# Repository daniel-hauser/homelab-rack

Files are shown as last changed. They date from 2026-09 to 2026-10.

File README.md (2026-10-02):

# Modular printable homelab rack

A parameterized, support-free OpenSCAD rack for a desktop stack today and
paired half-width modules in a standard 19-inch rack later. The current build
holds a UCG-Ultra, two USW-Ultra units, two Raspberry Pi 5 drawers, a removable
vent insert, and a UK-Ultra top carrier.

[**Start with `PRINT_THESE`**](PRINT_THESE/) ·
[3D viewer](https://daniel-hauser.github.io/homelab-rack/) ·
[rack render](renders/rack_preview_final.png) ·
[all build plates](renders/beds/all_beds.png)

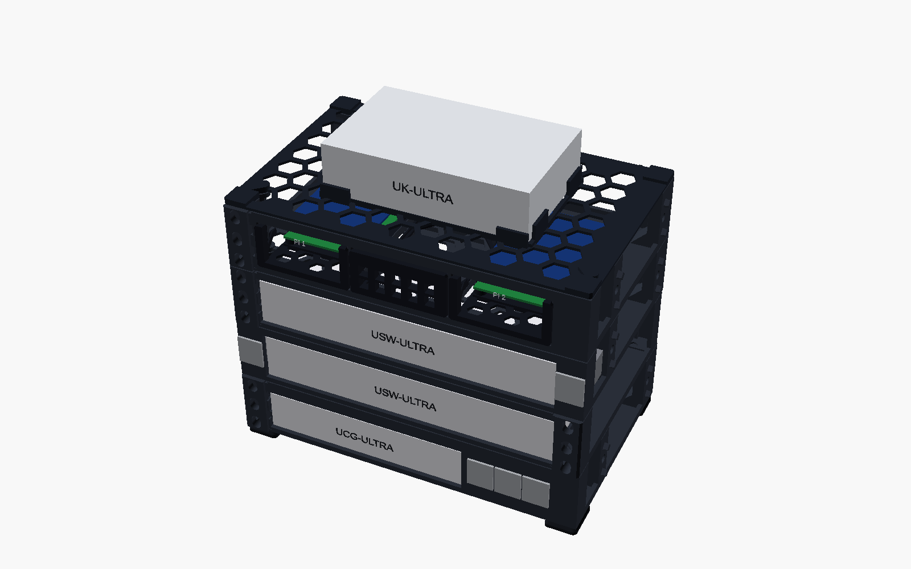
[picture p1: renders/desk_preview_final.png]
Assembled desktop homelab rack


## Choose the right project

### Already printed the older test-first plate

Open
[`PRINT_THESE\homelab-rack-Bambu-Studio-5-plates-NO-TEST.3mf`](PRINT_THESE/homelab-rack-Bambu-Studio-5-plates-NO-TEST.3mf)
or double-click `PRINT_THESE\OPEN_NO_TEST_PROJECT.cmd`. This is the optimized
production project: five A1 visits, no coupons, no polarity key, every final
assembly object exactly once, and one deliberately small manual support.
The optional
[`homelab-rack-Bambu-Studio-5-plates-NO-TEST-NO-SUPPORT.3mf`](PRINT_THESE/homelab-rack-Bambu-Studio-5-plates-NO-TEST-NO-SUPPORT.3mf)
preserves the native A/B baseline.

The project deliberately includes the current
`TEST_FIRST\04_Desktop_Feet_Set.stl`. The foot-to-stack peg and magnet geometry
changed, so feet from the older test plate are obsolete. No other test-only
artifact is required. The revised vent and both rear spines are already
included as final production objects.

### Waveshare PoE M.2 HAT+ (B) clearance replacement

If the dual-Pi chassis has not yet been printed, use
[`PRINT_THESE\REPLACEMENTS\PI-HAT-5MM-CLEARANCE`](PRINT_THESE/REPLACEMENTS/PI-HAT-5MM-CLEARANCE)
instead of the `04_Dual_Pi_Chassis.stl` object on Plate 3. This isolated
replacement raises only the two Pi openings from 30 mm to 35 mm for the HAT's
top power coils. The center vent opening, existing drawers, magnetic holders,
vent cartridge, rails, detents, and every stack/rack interface remain
unchanged; do not reprint the drawers or vent.

### Pi drawer 6 mm magnet-pocket replacement

If nominal 6 mm magnets do not enter the original drawer pockets, use
[`PRINT_THESE\REPLACEMENTS\PI-MAGNET-POCKET-6MM`](PRINT_THESE/REPLACEMENTS/PI-MAGNET-POCKET-6MM).
These replace both Pi drawers only. Their 6.60 mm straight glue-fit bores have
7.00 mm flared bed-face entrances to avoid elephant-foot constriction. Do not
press-fit magnets or drill through the 0.30 mm insulating roof; glue each
magnet against the roof after confirming polarity. The chassis and vent remain
unchanged.

### Complete remaining Pi hardware on one plate

For users who still need the corrected chassis and both corrected drawers, use
[`PRINT_THESE\REPLACEMENTS\PI-COMPLETE-SINGLE-PLATE`](PRINT_THESE/REPLACEMENTS/PI-COMPLETE-SINGLE-PLATE).
Its A1 project contains exactly those three objects on one plate, preserves the
validated chassis-only front-rail supports, and excludes the already-printed
vent.

| Plate | Objects |
| --- | --- |
| 1 | UCG-Ultra module; rear spine A |
| 2 | left USW-Ultra module; rear spine B |
| 3 | dual-Pi chassis; final rail-guided vent cartridge |
| 4 | right USW-Ultra module; Pi drawer 2 |
| 5 | UK-Ultra top; Pi drawer 1; revised desktop feet set |

The recommended targeted-support estimate is **517.58 g**, **173.53468 m**,
**417.39985 cm³**, and **23h13m19s** serial printing time. It adds **0.88 g**
and **6m23s** over the no-support baseline. Five plates remain the
geometric lower bound: the four chassis and the UK-Ultra top each have an
axis-aligned footprint wider than 241 mm and deeper than 150 mm, so no two fit
on one 256 × 256 mm A1 plate without overlap. Smaller parts occupy otherwise
unused bed regions around those five unavoidable footprints.

### Have not printed a test plate

Use the numbered files exactly as tracked. Do not use old aliases from previous
design revisions.

1. Open
   [`PRINT_THESE\TEST_FIRST\plate_1-test.3mf`](PRINT_THESE/TEST_FIRST/plate_1-test.3mf)
   in **Bambu Studio 02.08.02.61**, or import these ten STLs individually:

   - `PRINT_THESE\TEST_FIRST\01_Bay_Fit_Test.stl`
   - `PRINT_THESE\TEST_FIRST\02_Rear_Spine_A.stl`
   - `PRINT_THESE\TEST_FIRST\03_Rear_Spine_B.stl`
   - `PRINT_THESE\TEST_FIRST\04_Desktop_Feet_Set.stl`
   - `PRINT_THESE\TEST_FIRST\05_Magnet_Keystone_Peg_Test.stl`
   - `PRINT_THESE\TEST_FIRST\06_Vent_Insert.stl`
   - `PRINT_THESE\TEST_FIRST\07_Magnet_Polarity_Key.stl`
   - `PRINT_THESE\TEST_FIRST\08_Rack_Ear_Test.stl`
   - `PRINT_THESE\TEST_FIRST\09_Seam_Tower_Male_Test.stl`
   - `PRINT_THESE\TEST_FIRST\10_Seam_Tower_Female_Test.stl`

2. Break off and mate the stack tiles, then confirm the magnet pockets,
   keystone opening, Pi bay, seam towers, and rack-ear slots fit your hardware.
3. If the test plate succeeds, open the original test-first project,
   [`PRINT_THESE\homelab-rack-Bambu-Studio-6-plates.3mf`](PRINT_THESE/homelab-rack-Bambu-Studio-6-plates.3mf)
   or double-click `PRINT_THESE\OPEN_IN_BAMBU_STUDIO.cmd`.
4. Keep the rear spines flat on their broad faces. All tracked STLs are already
   exported in their intended print orientation.

Both projects use a Bambu Lab A1 with a 0.4 mm nozzle, 0.20 mm layers,
four walls, five top layers, four bottom layers, 20% gyroid, no supports, no
brim, and no skirt. The original six-plate magnetic-direction estimate is
**547.11 g**, **183.43948 m**, **441.22368 cm³**, and **24h43m51s** serial
printing time. Loose-magnet attraction to all four assembled Pi/HAT screw
heads has passed physical testing.

Bambu Studio reports a conservative “floating cantilever/regions” warning on the four
full-height chassis. Their maximum measured bridge is 17.52 mm. Print plate 1
first; if both seam-tower coupons are clean, keep automatic supports disabled
for the production chassis because generated supports obstruct functional
pockets and fill large open areas.

Native A/B slicing found no roof over the UCG or USW device cavities. The
17.51–17.52 mm upper paths are forward seam-side corner-cap bridges; the
seam-tower paths are shorter and farther rearward. The recommended project
adds one reachable 7 × 7 mm manual support column beneath that cap on the UCG.
It starts on the internal bottom cap because the
enclosed corner-post cavity is not reachable from the build plate.

The same seam-side location on each USW intersects its 34 mm-deep keystone
clearance; the opposite cap is the rack-ear/slot region. Both USWs therefore
remain unsupported rather than placing material in protected geometry for a
17.52 mm bridge that already passes the native bridge gate.

No support is generated around magnet pockets, peg/socket interfaces, seam
keys or towers, rack-ear slots, device rails, keystone openings, rear-spine
interfaces, or rear corner cavities. Support toolpath renders are under
`renders\supports-no-test`. The maximum classified bridge remains 18.84 mm
(the revised feet); supported chassis bridge lines remain classified as
bridges because of the removable 0.2 mm support gap.

Bambu clears the floating-region banner globally when manual support mode is
enabled, including on plates with no support extrusion. The A/B audit therefore
uses actual support toolpath segments—not warning disappearance—as its gate.

## Production STLs

`PRINT_THESE\STLs` contains only the ten required production files:

| File | Part |
| --- | --- |
| `01_UCG_Ultra.stl` | UCG-Ultra module |
| `02_USW_Ultra_Left.stl` | left USW-Ultra module |
| `03_USW_Ultra_Right.stl` | right USW-Ultra module |
| `04_Dual_Pi_Chassis.stl` | three-bay dual-Pi chassis |
| `05_Pi_Drawer_1.stl` | first Pi 5 drawer |
| `06_Pi_Drawer_2.stl` | second Pi 5 drawer |
| `07_Vent_Insert.stl` | center bay vent |
| `08_UK_Ultra_Top.stl` | desktop UK-Ultra carrier |
| `09_Rear_Spine_A.stl` | first rear spine |
| `10_Rear_Spine_B.stl` | second rear spine |

The two rear-spine files are intentionally identical; print both. The removable
feet are on the test-first plate.

## Design summary

- Half-module structural footprint: 241.30 × 150.00 mm.
- Paired width: 482.60 mm, with 465.10 mm rack mounting centers.
- Rack pitch: 44.45 mm; vertical hole centers: 6.350, 22.225, 38.100 mm.
- Universal magnets: 6 × 2 mm discs.
- Vertical registration: four printed peg/socket pairs plus four magnet pairs
  at every module-to-module or module-to-cap interface.
- Side joining: tapered diamond keys in reinforced seam towers.
- Paired seam: 0.0 mm designed face gap with 1.5 mm socket-depth reserve.
- Desktop stabilization: two removable rear spines and four removable feet.
- Pi mounting direction: four 6 × 2 mm magnets beneath the existing exposed
  lower screw heads, with printed side/corner locators carrying shear.
- Exposed chassis/top corners: 1.5 mm support-free chamfers.
- Pi and vent faceplates: 1.2 mm chamfers.
- Pi bay receiving lead-in: 1.2 mm deep at 45°, opening to 64.4 × 32.4 mm at
  the front while retaining the 62 × 30 mm friction opening behind it.
- Vent cartridge: 111 mm L-section side runners with 77 mm of guide-lip
  engagement and a light rear chevron that prevents racking.

Loose 6 × 2 mm magnets physically attract all four intended lower screw heads,
so screw ferromagnetism is accepted. The current CAD assumptions remain a
1.60 mm screw-head protrusion, 0.35 mm working gap, and 0.30 mm printed
insulating skin. Validate the actual installed gap and retention on the first
production drawer before printing the second. The through-floor concept
remains review-only because it requires replacement screws. Review CAD and the
full measurement list are in
[`REVIEW_ONLY\Pi_Mount_Alternatives`](REVIEW_ONLY/Pi_Mount_Alternatives).

Do not print another test coupon for the Pi mount. Print only
`PRINT_THESE\STLs\05_Pi_Drawer_1.stl` first with the pinned production profile,
install four magnets, seat the actual Pi/HAT assembly, and verify vertical
retention, locator engagement, drawer insertion, and the installed holder gap.
Print Drawer 2 only after that first article passes.

The vent is a proper track-guided cartridge rather than a shallow friction
plate. Its proven 64.5 × 30 mm face is unchanged. Two long L-section runners
engage the same floor tracks and guide lips as the Pi drawers, with 0.15 mm
side clearance and 2.0 mm reserve before the chassis rear stop. Two
inward-rising rear chevron legs prevent racking while leaving the airflow path
open. The cartridge prints face-down; each chevron leg grows from a supported
runner and keeps the maximum slicer-classified bridge below 20 mm.

The vent and both Pi cartridges share paired cam-release spring detents. The
detent pockets have 0.20 mm more depth than the 0.45 mm engagement, so they
provide pull-out retention without defining lateral alignment or
overconstraining the guide tracks. Push straight in until both sides click and
the receiving chamfer seats the faceplate flush. Remove by gripping the
projecting faceplate edges and pulling evenly; the rear ramps flex both
detents inward without tools.

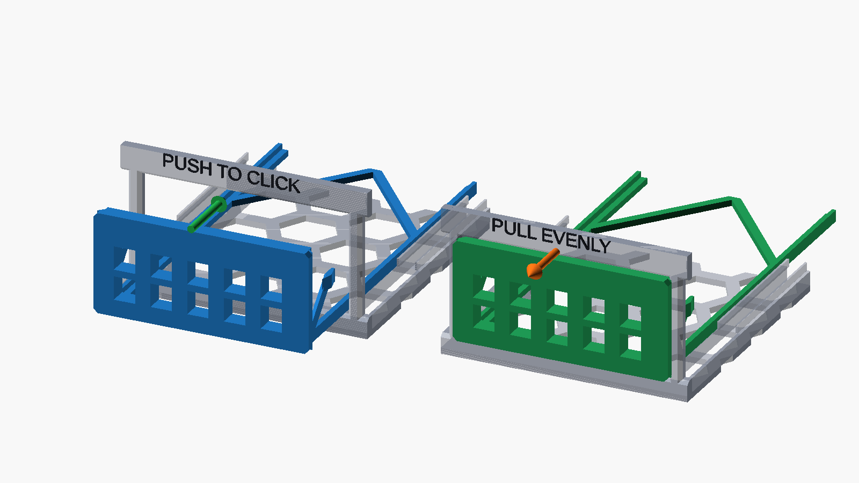
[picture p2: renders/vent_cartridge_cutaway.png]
Vent cartridge insertion and removal cutaway


Rack-stack magnets retain joints while printed pegs and keys carry lateral
loads. The Pi magnets provide vertical retention only; their printed locators
carry shear. A 19-inch installation still requires normal rack screws and cage
nuts. The UK-Ultra carrier assumes the OEM keyed backplate/cradle remains
attached.

Each vertical module interface has magnet centers at `(8,20)`, `(233.3,20)`,
`(8,142)`, and `(233.3,142)` mm, with independent peg/socket centers at
`(13,25)`, `(228.3,25)`, `(13,137)`, and `(228.3,137)` mm. The front pairs sit
behind the rack-slot cut depth; the closest magnet pocket retains 0.675 mm of
clearance and the closest socket retains 6.15 mm. The pattern is identical on
all full modules and the cap, so handed rack ears cannot create
magnet-to-empty-pocket pairs.

The desktop stack has 20 vertical magnet pairs: four at each of the four
module/cap joints plus four foot-to-bottom-module pairs. Two rear spines add
eight horizontal pairs, two per module. They align and brace the rear of the
four-module stack against racking but do not replace vertical corner
clamping. With eight Pi-retention magnets, the fully populated desktop build
uses 64 magnets.

Use one marked pole consistently by global axis:

- Stack and foot magnets: marked face points globally up (`+Z`).
- Module/spine rear magnets: marked face points toward the rack rear (`+Y`).
- Future side-seam magnets: marked face points toward rack right (`+X`).
- Pi magnets attract steel screw heads, so polarity is not functional; use the
  marked face upward for installation consistency.

Run the analytical checks before changing structural parameters:

```powershell
python .\rack_check.py
python .\load_check.py
python .\release_check.py
```

The current conservative screening reports a 2.6× honeycomb yield safety
factor, 93× stack-peg shear safety, 158.5× side-key shear safety, 7.9×
side-key interlayer bending safety, and 3.7× seam-tower interlayer safety.
These calculations do not replace a physical proof load.

## Reproduce or verify the release

The canonical geometry source is [`homelab_rack.scad`](homelab_rack.scad).
The release is pinned to:

- **OpenSCAD 2021.01** for STL and canonical CAD render generation.
- **Bambu Studio 02.08.02.61** for arrangement, slicing, estimates, and 3MF
  output.
- Python 3.13 with the pinned packages in `requirements.txt`.
- Node.js 22 with dependencies locked by `viewer\package-lock.json`.

Install Python dependencies:

```powershell
python -m pip install -r .\requirements.txt
```

Use one workflow for all OpenSCAD-derived release assets:

```powershell
# Export to ignored out\release-work and hash-check all tracked release assets.
.\export.ps1 -Mode Verify

# Deliberately replace the 20 numbered STLs, 11 viewer meshes,
# five canonical renders, and viewer estimate copy.
.\export.ps1 -Mode Generate
```

`Verify` compares fresh OpenSCAD exports with:

- all ten `PRINT_THESE\STLs` files using order-independent mesh hashes;
- all ten `PRINT_THESE\TEST_FIRST` files using order-independent mesh hashes;
- ten viewer production copies plus the viewer-only installed-feet model using
  the same geometry check;
- the five canonical CAD renders pixel-for-pixel, ignoring harmless PNG
  compression differences; and
- `viewer\public\estimate.json` against `slicer\release\estimate.json`.

The mesh hash ignores harmless STL facet ordering differences between
OpenSCAD runs. The tracked binary artifacts and their published SHA-256 hashes
are not changed by `Verify`.

### Bambu Studio / 3MF boundary

The repository automates same-named mesh replacement while preserving an
existing Bambu arrangement, but it does **not** automate Bambu Studio itself.
After changing geometry, first run `export.ps1 -Mode Generate`, then create
unsliced arrangement copies:

```powershell
python .\slicer\replace_3mf_meshes.py `
  .\PRINT_THESE\homelab-rack-Bambu-Studio-6-plates.3mf `
  .\out\homelab-rack-arranged-unsliced.3mf `
  .\PRINT_THESE\STLs .\PRINT_THESE\TEST_FIRST

python .\slicer\replace_3mf_meshes.py `
  .\PRINT_THESE\TEST_FIRST\plate_1-test.3mf `
  .\out\plate_1-arranged-unsliced.3mf `
  .\PRINT_THESE\STLs .\PRINT_THESE\TEST_FIRST
```

When only a subset changed, pass `--skip-missing` with a directory containing
only those STLs. This preserves the validated triangulation and arrangement of
every unaffected project mesh while still removing stale embedded G-code.

Open those copies in **Bambu Studio 02.08.02.61**, confirm the pinned A1
profile, slice every plate, inspect warnings, and save the final projects over
the tracked release 3MF files only after validation. This slicer step is
required: the replacement tool intentionally removes stale embedded G-code.

Raw `.gcode` and `.gcode.3mf` work products are ignored and are **not** tracked
release inputs. When fresh Bambu outputs exist locally, bridge audits and bed
renders can be regenerated with:

```powershell
python .\slicer\bridge_audit.py `
  .\slicer\production\desktop-strong `
  --project .\PRINT_THESE\homelab-rack-Bambu-Studio-6-plates.3mf `
  --output .\bridge-audit.json

python .\slicer\render_beds.py `
  .\slicer\production\desktop-strong `
  .\slicer\production\desktop-strong\desktop-strong.gcode.3mf `
  .\renders\beds
```

The separated five-plate evidence is tracked in:

- `slicer\release\no-test-estimate.json`
- `slicer\release\no-test-bridge-audit.json`
- `slicer\release\no-test-no-support-estimate.json`
- `slicer\release\no-test-no-support-bridge-audit.json`
- `slicer\release\no-test-support-ab-audit.json`
- `renders\beds-no-test`
- `renders\supports-no-test`

## Viewer

The public viewer is deployed by GitHub Pages without repository secrets:
<https://daniel-hauser.github.io/homelab-rack/>.

Local build:

```powershell
Set-Location .\viewer
npm ci
npm run build
```

The viewer uses relative asset paths, so it works under the repository Pages
subpath. Its displayed release totals come from
`viewer\public\estimate.json`, synchronized from the slicer estimate by
`export.ps1`.

## Dimensions to verify physically

Manufacturer envelopes are sufficient for the adjustable cradles, but verify
these before a long print:

- UCG-Ultra and USW-Ultra corner radii;
- assembled Pi 5, cooler, HAT, and NVMe height;
- keystone latch depth and panel-thickness requirements; and
- cable boot bend radius behind each rear-facing port.

Sources: [UCG-Ultra](https://techspecs.ui.com/unifi/cloud-gateways/ucg-ultra),
[USW-Ultra](https://techspecs.ui.com/unifi/switching/usw-ultra),
[UK-Ultra](https://techspecs.ui.com/unifi/wifi/uk-ultra),
[Waveshare PoE M.2 HAT+ (B)](https://www.waveshare.com/poe-m.2-hat-plus-b.htm),
[Raspberry Pi 5 mechanical drawing](https://datasheets.raspberrypi.com/rpi5/raspberry-pi-5-mechanical-drawing.pdf),
and [Bambu Lab A1](https://bambulab.com/en/a1/tech-specs).

## License

See [`LICENSE.md`](LICENSE.md). Hardware sources and generated hardware
artifacts are CERN-OHL-S-2.0, software/tooling is MIT, and documentation and
rendered images are CC-BY-4.0.

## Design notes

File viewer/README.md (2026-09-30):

# Homelab Rack 3D Viewer

Focused Vite + TypeScript + Three.js viewer for the validated ten-part homelab
rack production set. Dependencies and STL assets are local; the deployed site
makes no CDN requests.

## Local development

```powershell
npm ci
npm run dev
```

Production build:

```powershell
npm run build
```

The output is written to `dist`. Vite uses `base: "./"`, so scripts, images, and models resolve beneath any GitHub Pages repository subpath.

## GitHub Pages integration

The repository workflow at `.github/workflows/pages.yml` builds this directory
with Node 22 and publishes `viewer/dist` through GitHub's OIDC-backed Pages
deployment. It uses no repository secrets.

No repository name or fixed `/repo/` base path is embedded. Relative Vite paths
allow the site to run at `https://daniel-hauser.github.io/homelab-rack/`.

## Production data

- Printer: Bambu Lab A1, 0.4 mm nozzle
- Profile: 0.20 mm layers, four walls, five top/bottom layers, 20% gyroid
- Supports/brim/skirt: none
- Candidate total: 547.11 g, 183.43948 m, 441.22368 cm³, 24h43m51s
- Magnets: universal 6 × 2 mm discs
- Module depth: 150 mm

Dimensions shown in the viewer are calculated STL bounding boxes. Release
totals are loaded from `public/estimate.json`, which `..\export.ps1`
synchronizes with `slicer/release/estimate.json`.

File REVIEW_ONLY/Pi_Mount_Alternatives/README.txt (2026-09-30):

PI MOUNT ALTERNATIVES - REVIEW ONLY
===================================

These files document the selected magnetic Raspberry Pi 5 mounting direction
and its through-floor fallback. Loose-magnet attraction has passed on all four
assembled screw heads. Exact installed holder gap and retention remain a
production Drawer 1 first-article check.

A_Magnetic_Cradle_Review.stl - selected direction, physically gated
  Four 6 x 2 mm magnet glue pockets align to the accessible lower screw heads
  on the official 58 x 49 mm Pi pattern. A provisional 0.30 mm printed
  insulating skin separates each magnet from the screw-head recess. Four side
  tabs and two rear-corner stops carry shear while leaving the central rear
  microSD area open.

  Preview-only assumptions:
  - installed screw-head protrusion below PCB: 1.60 mm;
  - target screw-head-to-skin gap: 0.35 mm;
  - printed insulating skin: 0.30 mm;
  - magnet pocket diameter: 6.25 mm;
  - magnet position: Z 2.55 to 4.55 mm above the drawer underside.

  Install each magnet from the drawer underside, hold it against the printed
  roof while epoxy cures, and optionally fill the remaining access recess
  flush. Polarity does not affect attraction to steel; install all four with
  the same pole facing the PCB for consistency. Attraction to all four screw
  heads has passed; validate the installed gap on production Drawer 1.

B_Through_Floor_M2.5_Review.stl - review fallback only
  Four M2.5 clearance holes and recessed head counterbores align to the same
  58 x 49 mm pattern. The replacement screw passes through the 1.20 mm local
  printed shoulder, the Pi PCB, and into the existing female HAT standoff.
  The screw head remains recessed above the drawer underside.

  Required replacement length:
    measured existing under-head screw length + exactly 1.20 mm

  No purchased screw length is specified until the existing screw length,
  head geometry, and usable female-standoff thread depth are measured.

Required user measurements and checks
-------------------------------------
1. Passed: a loose 6 x 2 mm magnet attracts each of the four exposed lower
   screw heads individually.
2. Measure each screw head's protrusion below the PCB; report the minimum and
   maximum, in mm.
3. Measure screw-head diameter and height, in mm.
4. Measure the existing underside screw length under the head, thread
   diameter/pitch, and the usable female-standoff thread depth.
5. Confirm the actual magnets' diameter and thickness and, if known, grade.
6. Weigh the complete Pi + cooler + HAT + NVMe assembly if a scale is
   available; otherwise the retention calculation will retain a conservative
   0.20 kg design mass.

The OpenSCAD source keeps both concepts parameterized through the shared
pi_cartridge() and pi_cartridge_retention_cuts() modules.

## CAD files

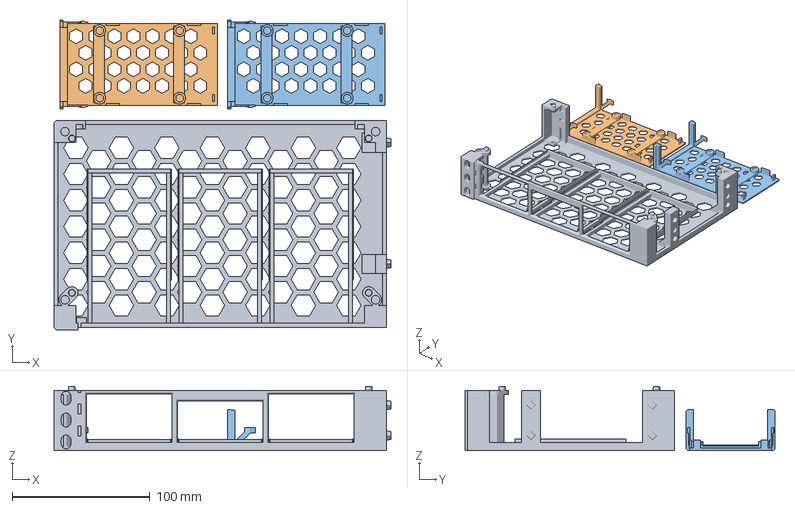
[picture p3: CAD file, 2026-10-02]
PRINT_THESE/REPLACEMENTS/PI-COMPLETE-SINGLE-PLATE/homelab-rack-Pi-Complete-Single-Plate-A1.3mf
244.5 x 225.0 x 46.7 mm
04_Dual_Pi_Chassis_5mm_HAT_Clearance.stl
05_Pi_Drawer_1_6mm_Magnet_Fit.stl
06_Pi_Drawer_2_6mm_Magnet_Fit.stl

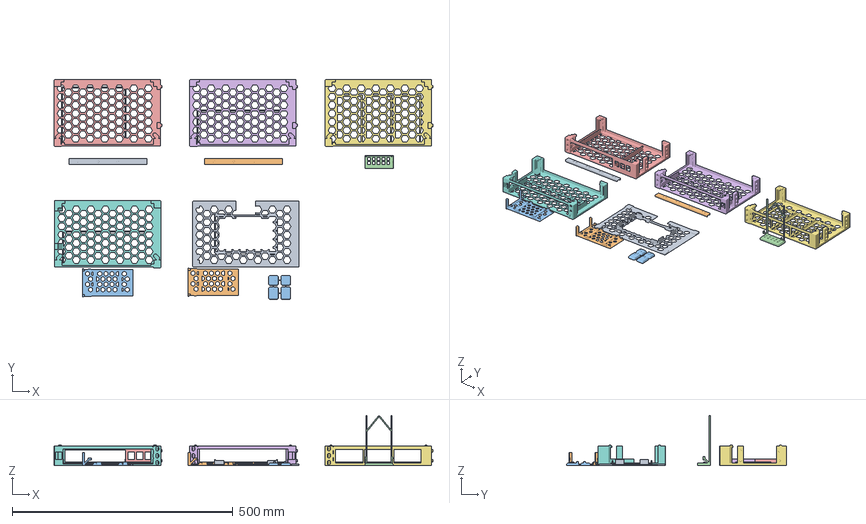
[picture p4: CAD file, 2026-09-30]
PRINT_THESE/homelab-rack-Bambu-Studio-5-plates-NO-TEST.3mf
858.9 x 498.2 x 113.4 mm
09_Rear_Spine_A.stl
10_Rear_Spine_B.stl
04_Desktop_Feet_Set.stl
07_Vent_Insert.stl
01_UCG_Ultra.stl
02_USW_Ultra_Left.stl
04_Dual_Pi_Chassis.stl
03_USW_Ultra_Right.stl
08_UK_Ultra_Top.stl
05_Pi_Drawer_1.stl
06_Pi_Drawer_2.stl

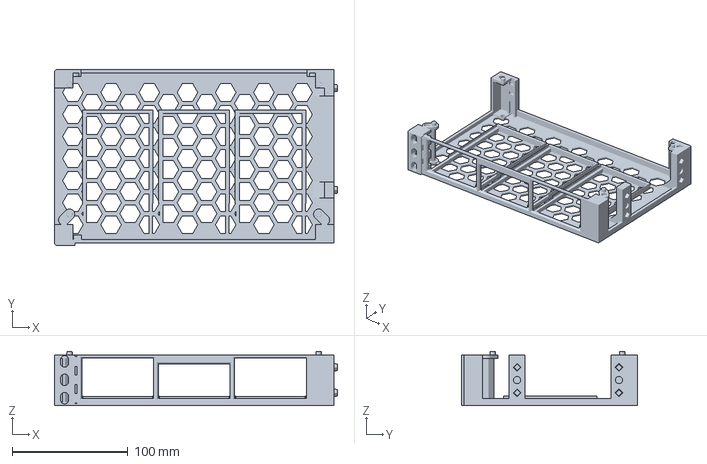
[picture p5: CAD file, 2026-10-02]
PRINT_THESE/REPLACEMENTS/PI-HAT-5MM-CLEARANCE/homelab-rack-Dual-Pi-Chassis-5mm-HAT-Clearance.3mf
244.5 x 152.0 x 46.7 mm

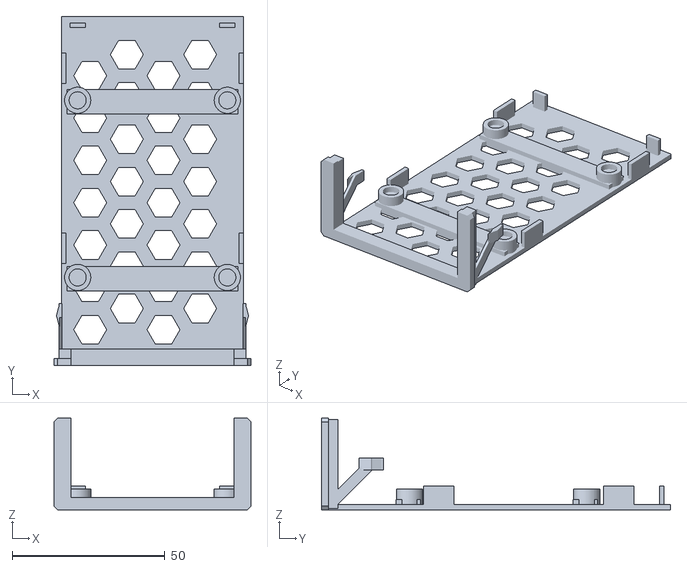
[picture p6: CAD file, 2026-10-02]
PRINT_THESE/REPLACEMENTS/PI-MAGNET-POCKET-6MM/05_Pi_Drawer_1_6mm_Magnet_Fit.stl
64.5 x 114.4 x 30.0

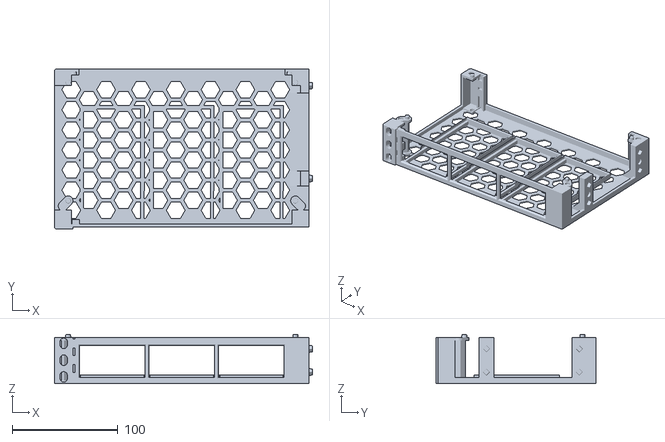
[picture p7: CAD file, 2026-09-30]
PRINT_THESE/STLs/04_Dual_Pi_Chassis.stl
244.5 x 152.0 x 46.7

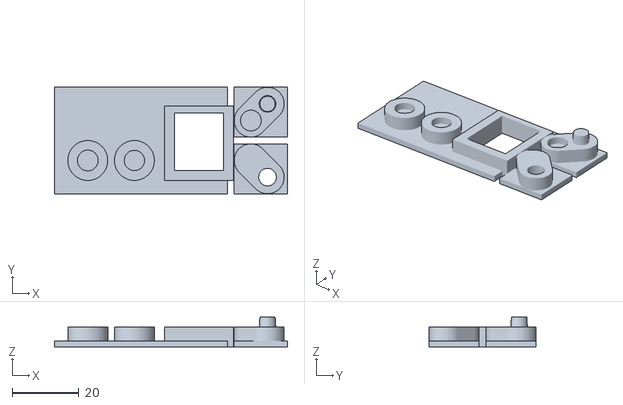
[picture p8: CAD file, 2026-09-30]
PRINT_THESE/TEST_FIRST/05_Magnet_Keystone_Peg_Test.stl
70.0 x 32.0 x 9.00

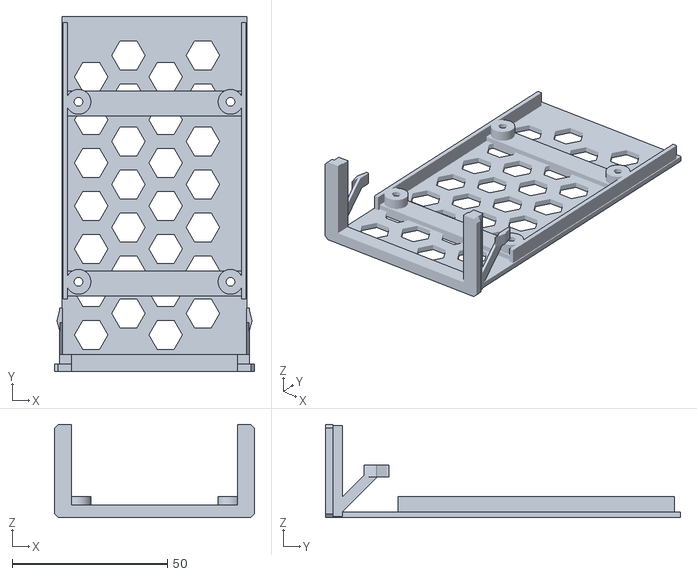
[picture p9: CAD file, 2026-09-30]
REVIEW_ONLY/Pi_Mount_Alternatives/B_Through_Floor_M2.5_Review.stl
64.5 x 114.4 x 30.0

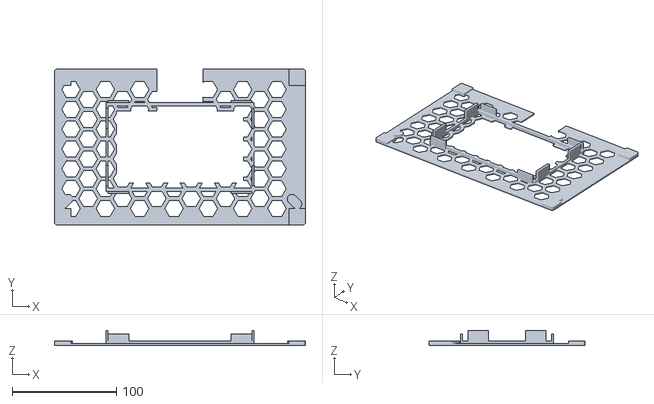
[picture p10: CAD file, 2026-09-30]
viewer/public/models/08_UK_Ultra_Top.stl
241.3 x 150.0 x 14.0

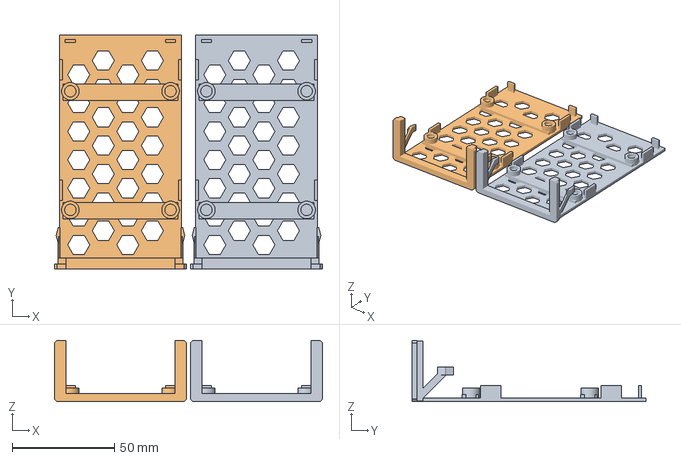
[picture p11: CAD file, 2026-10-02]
PRINT_THESE/REPLACEMENTS/PI-MAGNET-POCKET-6MM/homelab-rack-Pi-Drawers-6mm-Magnet-Fit.3mf
131.0 x 114.4 x 30.0 mm
05_Pi_Drawer_1_6mm_Magnet_Fit.stl
06_Pi_Drawer_2_6mm_Magnet_Fit.stl

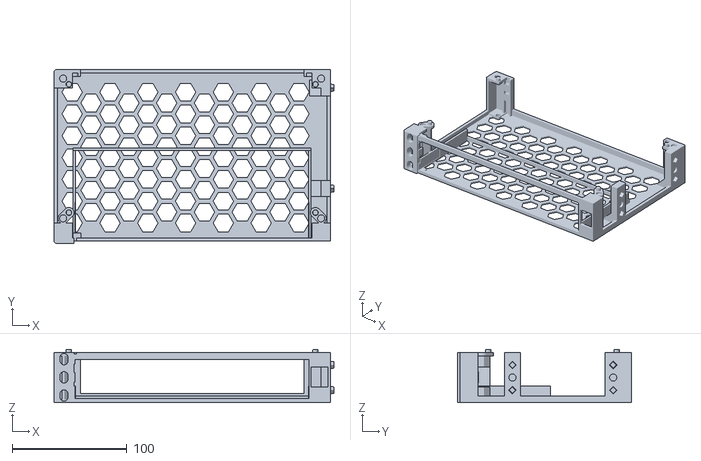
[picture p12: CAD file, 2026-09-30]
PRINT_THESE/STLs/02_USW_Ultra_Left.stl
244.5 x 152.0 x 46.7

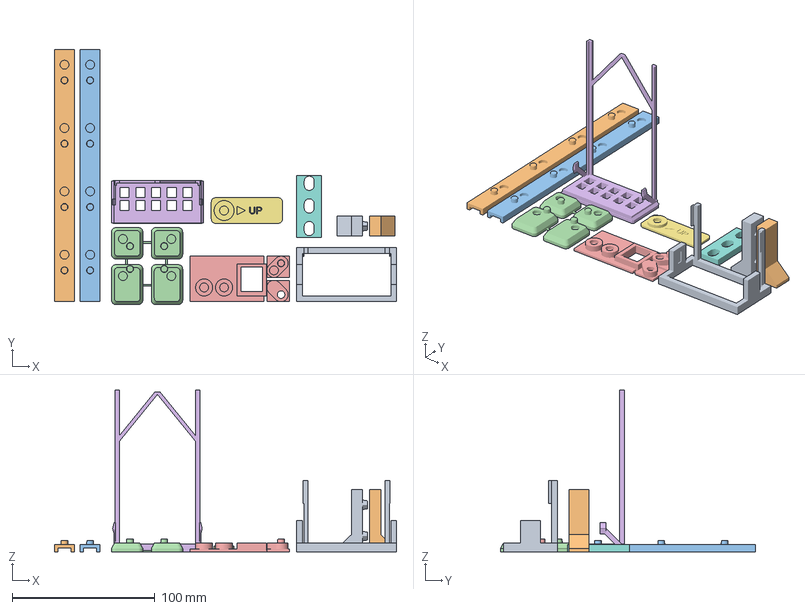
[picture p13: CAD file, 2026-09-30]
PRINT_THESE/TEST_FIRST/plate_1-test.3mf
240.0 x 179.1 x 113.4 mm
01_Bay_Fit_Test.stl
02_Rear_Spine_A.stl
03_Rear_Spine_B.stl
04_Desktop_Feet_Set.stl
05_Magnet_Keystone_Peg_Test.stl
06_Vent_Insert.stl
07_Magnet_Polarity_Key.stl
08_Rack_Ear_Test.stl
09_Seam_Tower_Male_Test.stl
10_Seam_Tower_Female_Test.stl

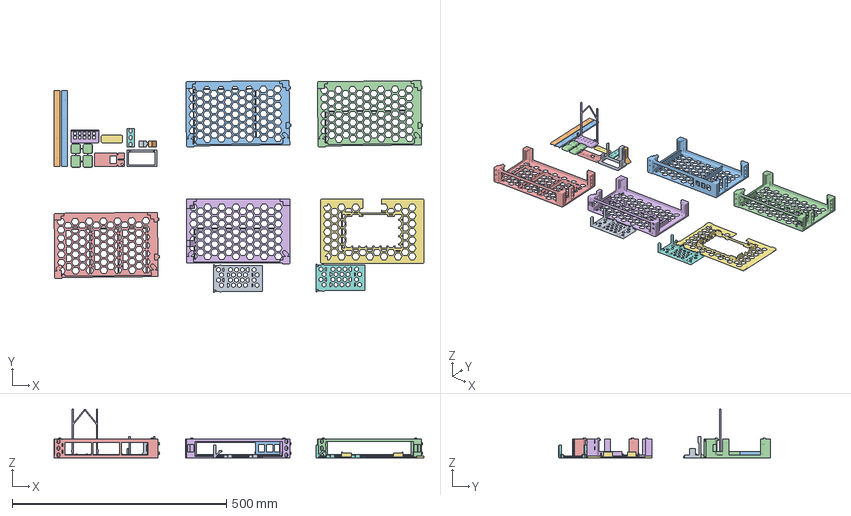
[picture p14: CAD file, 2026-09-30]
PRINT_THESE/homelab-rack-Bambu-Studio-6-plates.3mf
863.4 x 493.9 x 113.4 mm
01_Bay_Fit_Test.stl
02_Rear_Spine_A.stl
03_Rear_Spine_B.stl
04_Desktop_Feet_Set.stl
05_Magnet_Keystone_Peg_Test.stl
06_Vent_Insert.stl
07_Magnet_Polarity_Key.stl
08_Rack_Ear_Test.stl
09_Seam_Tower_Male_Test.stl
10_Seam_Tower_Female_Test.stl
01_UCG_Ultra.stl
02_USW_Ultra_Left.stl
04_Dual_Pi_Chassis.stl
03_USW_Ultra_Right.stl
08_UK_Ultra_Top.stl
05_Pi_Drawer_1.stl
06_Pi_Drawer_2.stl

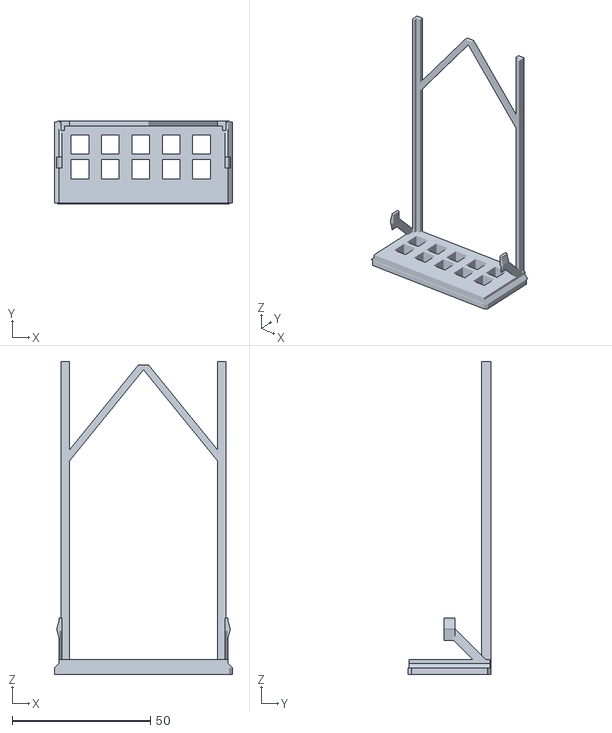
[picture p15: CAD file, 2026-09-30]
PRINT_THESE/STLs/07_Vent_Insert.stl
64.5 x 30.0 x 113.4

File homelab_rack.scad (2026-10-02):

/*
  SPDX-License-Identifier: CERN-OHL-S-2.0

  Modular half-width homelab rack for a Bambu Lab A1.

  Coordinate system:
    X = module width, Y = depth (front at 0), Z = height.

  Export examples:
    openscad -o out/ucg_left.stl -D 'part="ucg_left"' homelab_rack.scad
    openscad -o out/desk_preview.png --render -D 'part="desk_preview"' homelab_rack.scad
*/

$fn = 48;

part = "desk_preview";

// Printer/material tuning
fit_clearance = 0.35;
peg_clearance = 0.30;
magnet_clearance = 0.25;
keystone_clearance = 0.30;

// EIA-310 / IEC 60297
rack_width = 482.60;
half_width = rack_width / 2;
rack_hole_centers = 465.10;
rack_hole_edge = (rack_width - rack_hole_centers) / 2;
u_height = 44.45;
panel_height = 43.70;
rack_hole_z = [6.35, 22.225, 38.10];
rack_ear_width = 17.5;
rack_ear_relief = 2.0;
rack_ear_forward = 2.0;
rack_ear_thickness = 5.0;

// Shared module geometry
module_depth = 150;
base_thickness = 1.8;
front_thickness = 3.0;
rear_thickness = 3.0;
corner_size = 16;
exterior_chamfer = 1.5;
faceplate_chamfer = 1.2;

// User-available magnets
stack_magnet_d = 6;
stack_magnet_h = 2;
stack_feature_boss_d = 9;
stack_feature_tower_wall = 2.4;
stack_peg_positions = [
    [13, 25],
    [half_width - 13, 25],
    [13, module_depth - 13],
    [half_width - 13, module_depth - 13]
];
stack_magnet_positions = [
    [8, 20],
    [half_width - 8, 20],
    [8, module_depth - 8],
    [half_width - 8, module_depth - 8]
];
side_magnet_d = 6;
side_magnet_h = 2;
side_key_root = 7.2;
side_key_tip = 5.6;
side_key_length = 3.2;
side_key_socket_extra = 1.7;
side_join_y = [46, module_depth - 16];
side_join_tower_w = 8;
side_join_tower_d = 14;
side_join_gusset_run = 10;

// Verified equipment envelopes
ucg_size = [141.8, 127.6, 30.0];
usw_size = [203.0, 76.0, 33.0];
pi_board = [56.0, 85.0, 1.6]; // Rotated: connector edge faces front
poe_hat_plan = [56.0, 85.0];  // Waveshare PoE M.2 HAT+ (B)
pi_side_margin = 20.0;
pi_mount_height = 6.8;
pi_mount_boss_d = 8.0;
pi_mount_screw_d = 2.8;
pi_mount_head_clearance_d = 5.6;
pi_mount_shoulder = 1.2;
pi_mount_pattern_x = [3.5, 52.5];
pi_mount_pattern_y = [3.5, 61.5];
pi_locator_clearance = 0.30;

// Magnetic production direction; dimensions remain physically gated.
pi_magnetic_assumed_screw_head_d = 5.0;
pi_magnetic_assumed_screw_head_h = 1.6;
pi_magnetic_target_gap = 0.35;
pi_magnetic_insulating_skin = 0.30;
pi_magnet_pocket_d = stack_magnet_d + magnet_clearance;
pi_magnet_fit_pocket_d = 6.60;
pi_magnet_fit_mouth_d = 7.00;
pi_magnet_fit_leadin_h = 0.70;
pi_magnet_fit_boss_d = 8.60;
bay_count = 3;
bay_width = 62.0;
bay_gap = 4.0;
bay_start = (
    half_width - bay_count * bay_width - (bay_count - 1) * bay_gap
) / 2;
bay_opening_z = 6.0;
bay_opening_h = 30.0;
pi_hat_clearance_extra = 5.0;
bay_depth = 112.0;
bay_clearance = 0.40;
cartridge_detent_z = 13.0;
cartridge_detent_h = 4.0;
cartridge_detent_arm_t = 1.0;
cartridge_detent_arm_y = 2.2;
cartridge_detent_arm_len = 15.8;
cartridge_detent_peak_y = 14.0;
cartridge_detent_protrusion = 0.45;
cartridge_detent_pocket_depth = 0.65;
vent_cartridge_depth = bay_depth - 1.0;
vent_runner_x = bay_clearance + 0.8;
vent_runner_w = 3.0;
vent_runner_floor_t = 1.8;
vent_runner_h = 3.4;
vent_chevron_w = 1.8;
vent_chevron_start_y = vent_cartridge_depth - 36.0;
vent_chevron_peak_y = vent_cartridge_depth - 3.0;
bay_fit_coupon_depth = 50.0;
uk_ultra_size = [137.0, 84.0, 34.0];
uk_ultra_clearance = 1.20;

keystone_cutout = [
    14.5 + keystone_clearance,
    16.0 + keystone_clearance
];
keystone_top_clearance = 1.0;
keystone_body = [16.5, 32.0, 18.0];
face_clearance_depth = 34.0;

module rack_slot(x, z, length = 10.0, diameter = 7.0) {
    hull() {
        for (dz = [-length / 2 + diameter / 2, length / 2 - diameter / 2])
            translate([x, corner_size + 0.2, z + dz])
                rotate([90, 0, 0])
                    cylinder(
                        d = diameter,
                        h = corner_size + rack_ear_forward + 0.4
                    );
    }
}

module face_cutout(x, z, width, height) {
    translate([x, -0.2, z])
        cube([width, face_clearance_depth + 0.4, height]);
}

module bay_face_cutout(x, z, height = bay_opening_h) {
    face_cutout(x, z, bay_width, height);

    hull() {
        translate([
            x - faceplate_chamfer,
            -0.2,
            z - faceplate_chamfer
        ])
            cube([
                bay_width + 2 * faceplate_chamfer,
                0.01,
                height + 2 * faceplate_chamfer
            ]);
        translate([x, faceplate_chamfer, z])
            cube([bay_width, 0.01, height]);
    }
}

module bay_service_detent_pockets(x, z) {
    pocket_y = cartridge_detent_peak_y - 4.2;
    pocket_len = 8.4;

    translate([
        x - cartridge_detent_pocket_depth,
        pocket_y,
        z + cartridge_detent_z
    ])
        cube([
            cartridge_detent_pocket_depth + 0.1,
            pocket_len,
            cartridge_detent_h
        ]);
    translate([
        x + bay_width - 0.1,
        pocket_y,
        z + cartridge_detent_z
    ])
        cube([
            cartridge_detent_pocket_depth + 0.1,
            pocket_len,
            cartridge_detent_h
        ]);
}

module cartridge_service_detents() {
    left_x = bay_clearance;
    right_x = bay_width - bay_clearance;
    detent_end_y = cartridge_detent_arm_y
        + cartridge_detent_arm_len;
    slope_end_y = cartridge_detent_peak_y - 0.6;
    root_z = base_thickness;

    for (x = [
        left_x,
        right_x - cartridge_detent_arm_t
    ]) {
        hull() {
            translate([
                x,
                cartridge_detent_arm_y,
                root_z
            ])
                cube([
                    cartridge_detent_arm_t,
                    0.8,
                    cartridge_detent_h
                ]);
            translate([
                x,
                slope_end_y,
                cartridge_detent_z
            ])
                cube([
                    cartridge_detent_arm_t,
                    0.8,
                    cartridge_detent_h
                ]);
        }
        translate([
            x,
            slope_end_y,
            cartridge_detent_z
        ])
            cube([
                cartridge_detent_arm_t,
                detent_end_y - slope_end_y,
                cartridge_detent_h
            ]);
    }

    translate([0, 0, cartridge_detent_z])
        linear_extrude(height = cartridge_detent_h) {
            polygon([
                [left_x + 0.2, cartridge_detent_peak_y - 4],
                [left_x + 0.2, detent_end_y],
                [
                    -cartridge_detent_protrusion,
                    cartridge_detent_peak_y
                ]
            ]);
            polygon([
                [right_x - 0.2, cartridge_detent_peak_y - 4],
                [
                    bay_width + cartridge_detent_protrusion,
                    cartridge_detent_peak_y
                ],
                [right_x - 0.2, detent_end_y]
            ]);
        }
}

module bay_guide_lips(
    x,
    z,
    start_y = face_clearance_depth,
    length = bay_depth - face_clearance_depth + front_thickness
) {
    guide_w = 0.65;

    for (guide_x = [
        x + bay_clearance,
        x + bay_width - bay_clearance - guide_w
    ])
        translate([guide_x, start_y, z])
            cube([guide_w, length, 2.4]);
}

module keystone_cutout_at(x, z = 13.7) {
    face_cutout(
        x,
        z,
        keystone_cutout[0],
        keystone_cutout[1] + keystone_top_clearance
    );
}

module xy_corner_chamfer_cut(chamfer, height) {
    linear_extrude(height = height)
        polygon([
            [-0.2, -0.2],
            [chamfer + 0.2, -0.2],
            [-0.2, chamfer + 0.2]
        ]);
}

module rectangular_corner_chamfer_cuts(
    width,
    depth,
    height,
    chamfer = exterior_chamfer
) {
    for (x_side = [0, 1])
        for (y_side = [0, 1])
            translate([
                x_side ? width : 0,
                y_side ? depth : 0,
                -0.2
            ])
                mirror([x_side, 0, 0])
                    mirror([0, y_side, 0])
                        xy_corner_chamfer_cut(
                            chamfer,
                            height + 0.4
                        );
}

module exposed_module_corner_chamfer_cuts(hand) {
    outer_x = hand == "left" ? 0 : half_width;

    for (front = [0, 1])
        translate([
            outer_x,
            front ? -rack_ear_forward : module_depth,
            -0.2
        ])
            mirror([hand == "right" ? 1 : 0, 0, 0])
                mirror([0, front ? 0 : 1, 0])
                    xy_corner_chamfer_cut(
                        exterior_chamfer,
                        panel_height + 3.6
                    );
}
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

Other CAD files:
PRINT_THESE/homelab-rack-Bambu-Studio-5-plates-NO-TEST-NO-SUPPORT.3mf
PRINT_THESE/REPLACEMENTS/PI-HAT-5MM-CLEARANCE/04_Dual_Pi_Chassis_5mm_HAT_Clearance.stl
REVIEW_ONLY/Pi_Mount_Alternatives/A_Magnetic_Cradle_Review.stl
viewer/public/models/05_Pi_Drawer_1.stl
PRINT_THESE/REPLACEMENTS/PI-MAGNET-POCKET-6MM/06_Pi_Drawer_2_6mm_Magnet_Fit.stl
PRINT_THESE/STLs/01_UCG_Ultra.stl
PRINT_THESE/STLs/03_USW_Ultra_Right.stl
PRINT_THESE/STLs/05_Pi_Drawer_1.stl
PRINT_THESE/STLs/06_Pi_Drawer_2.stl
PRINT_THESE/STLs/09_Rear_Spine_A.stl
PRINT_THESE/STLs/10_Rear_Spine_B.stl
PRINT_THESE/TEST_FIRST/01_Bay_Fit_Test.stl
PRINT_THESE/TEST_FIRST/02_Rear_Spine_A.stl
PRINT_THESE/TEST_FIRST/03_Rear_Spine_B.stl
PRINT_THESE/TEST_FIRST/04_Desktop_Feet_Set.stl
PRINT_THESE/TEST_FIRST/07_Magnet_Polarity_Key.stl
PRINT_THESE/TEST_FIRST/08_Rack_Ear_Test.stl
PRINT_THESE/TEST_FIRST/09_Seam_Tower_Male_Test.stl
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

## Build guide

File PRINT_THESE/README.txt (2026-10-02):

HOMELAB RACK - PRINT-ONLY PACKAGE
=================================

The "STLs" folder contains exactly the 10 parts needed for the current
desktop rack. It contains no blanks, alternate variants, or fit-test coupons.

ALREADY PRINTED THE OLDER TEST PLATE
====================================

Double-click OPEN_NO_TEST_PROJECT.cmd or open
homelab-rack-Bambu-Studio-5-plates-NO-TEST.3mf.

Use this five-plate project for the fewest printer visits. It excludes every
fit coupon, seam coupon, rack-ear coupon, polarity key, and old test-only part.
It contains every final assembly object exactly once. The primary NO-TEST
project is the recommended targeted-support variant. Use
homelab-rack-Bambu-Studio-5-plates-NO-TEST-NO-SUPPORT.3mf only if you
deliberately want the native A/B baseline.

The revised 04_Desktop_Feet_Set.stl is intentionally included. The foot stack
peg and magnet geometry changed, so feet from the older test plate are
obsolete. No other test-only artifact is needed: the final rail-guided vent
and both rear spines are already included.

WAVESHARE POE M.2 HAT+ (B) REPLACEMENT

If the dual-Pi chassis has not been printed, use:

  REPLACEMENTS\PI-HAT-5MM-CLEARANCE\

Print its standalone 3MF instead of the old chassis object on Plate 3. Do not
reprint either Pi drawer or the vent. The replacement changes only the outer
Pi insertion openings from 30 mm to 35 mm.

PI DRAWER 6 MM MAGNET-POCKET REPLACEMENT

If nominal 6 mm magnets do not enter the printed drawer pockets, use:

  REPLACEMENTS\PI-MAGNET-POCKET-6MM\

This package replaces both drawers only. The chassis and vent remain unchanged.
Use glue; do not press-fit magnets and do not drill through the insulating roof.

PI COMPLETE SINGLE-PLATE PROJECT

If the corrected chassis and both corrected drawers are still unprinted, use:

  REPLACEMENTS\PI-COMPLETE-SINGLE-PLATE\

This single A1 plate contains those three objects only. It excludes the vent
and preserves targeted support only beneath the chassis's raised front rails.

Plate 1: UCG-Ultra module + rear spine A
Plate 2: left USW-Ultra module + rear spine B
Plate 3: dual-Pi chassis + final rail-guided vent cartridge
Plate 4: right USW-Ultra module + Pi drawer 2
Plate 5: UK-Ultra top + Pi drawer 1 + revised desktop feet set

Targeted-support estimate: 517.58 g PLA and 23h13m19s serial printing time,
0.88 g and 6m23s above the no-support baseline. The maximum classified bridge
is 18.84 mm.

Native A/B analysis found no UCG/USW roof over the device cavity. The concerning
17.51-17.52 mm paths are the forward seam-side corner-post top caps. One small
7 x 7 mm manual support column is generated under that cap on the UCG. It
starts on the internal bottom cap because build-plate-only support
cannot enter the enclosed corner-post cavity. Pull it out through the open
front/seam-side corner after printing.

The equivalent seam-side location on each USW overlaps the 34 mm-deep keystone
clearance, and the opposite side is the rack-ear/slot region. Both USWs remain
unsupported rather than violating those protected interfaces for a validated
17.52 mm bridge.

There is no support around magnet pockets, pegs/sockets, seam keys/towers,
rack-ear slots, device rails, keystone openings, rear-spine interfaces, or
rear corner cavities. Only plate 1 receives support.
Bambu clears floating-region banners globally in manual-support mode; the
tracked audit verifies actual support extrusion rather than relying on banners.

Five plates are the geometric minimum. Each of the four chassis and the
UK-Ultra top is over 241 mm wide and at least 150 mm deep in its validated
axis-aligned print orientation, so no two can share a 256 x 256 mm A1 bed.

HAVE NOT PRINTED A TEST PLATE
==============================

Fastest way to load the original test-first workflow:

1. Extract the ZIP.
2. Double-click OPEN_IN_BAMBU_STUDIO.cmd.
3. Bambu Studio opens homelab-rack-Bambu-Studio-6-plates.3mf with a useful
   validation plate first, followed by five production plates.
4. Confirm your installed A1 0.4 mm printer and actual filament before
   printing. The included project is already sliced natively by Bambu Studio.

Both projects were prepared with an A1 0.4 mm nozzle, 0.20 mm layers, 4 walls,
5 top layers, 4 bottom layers, 20% gyroid, no supports, no brim, and no skirt.

Loose magnets physically attract all four intended assembled Pi/HAT screw
heads, so screw ferromagnetism is accepted. Do not print another test coupon
for the Pi mount. Print only STLs\05_Pi_Drawer_1.stl first with the pinned
profile, install four magnets, seat the actual Pi/HAT assembly, and verify
retention, locator engagement, drawer insertion, and the installed holder gap.
Print Drawer 2 only after this first article passes.

After Drawer 1 passes, print the tracked project in this order: plate 2 UCG,
plate 3 left USW, plate 4 dual-Pi chassis, plate 5 right USW plus Drawer 2,
then plate 6 UK-Ultra top with its already-printed Drawer 1 object disabled.
Plate 1 is the existing test-first plate and does not need to be reprinted.

Candidate total: 547.11 g PLA and 24h43m51s across six plates. Plate 1 is
67.80 g / 3h29m28s and includes both rear spines, the vent, all four feet,
the polarity key, and the required fit coupons.

Exposed chassis and UK-Ultra cap corners use restrained 1.5 mm support-free
chamfers. The removable Pi and vent faceplates use 1.2 mm chamfers. Functional
seam, rack, bay, and rear-spine dimensions are unchanged. The two front
stacking pairs were relocated rearward to clear the full-depth rack slots.

This revision uses reinforced 8 x 14 mm seam towers with 45-degree floor
buttresses. The reinforcement adds 17.75 g across the complete rack.
Physical coupon testing confirmed clean seam-tower prints and easy engagement.
The paired modules have a 0.0 mm designed face gap and 1.5 mm of axial socket
reserve so the tower faces can close without the keys bottoming out.

The two rear-spine STL files are intentionally identical: print one of each.

The rack-ear profile visually matches existing rack hardware and retains the
validated 482.60 mm outer width and 465.10 mm mounting centers.

The Pi drawers use four 6 x 2 mm magnet pockets beneath the existing lower
screw heads, with printed side/corner locators carrying shear. Loose-magnet
attraction has passed on all four assembled screw heads. The current CAD
assumes 1.60 mm protrusion, a 0.35 mm working gap, and a 0.30 mm insulating
skin; the exact installed gap remains a Drawer 1 first-article check. The
through-floor alternative remains review-only.

The vent is now a lightweight full-depth cartridge rather than a shallow
friction plate. Its proven 64.5 x 30 mm face is unchanged. Two 111 mm
L-section runners engage the same chassis tracks as the Pi drawers for 77 mm,
with 0.15 mm side clearance and 2.0 mm reserve before the rear stop. A light
rear chevron prevents racking without blocking airflow. Print the cartridge
face-down as exported; both chevron legs grow inward from supported runners.

The vent and Pi cartridges click into paired service detents behind the front
face. Their 0.65 mm pockets provide 0.20 mm relief beyond the 0.45 mm local
engagement, so the detents retain without overconstraining the guide tracks.
Push straight in until both sides click. Remove by gripping the projecting
faceplate edges and pulling evenly; rear ramps cam the spring arms inward. The
validated 62 x 30 mm opening is unchanged, and its 1.2 mm receiving chamfer
seats the faceplate flush.

Every vertical module/cap joint has four magnet pairs and four independent
peg/socket pairs. The front pairs are relocated behind the rack-slot cut depth;
handed rack ears therefore cannot open a pocket or create a magnet-to-empty
pair. Four additional pairs clamp the removable feet to the bottom module.

The two rear spines add two horizontal magnet/peg pairs per module. They align
and brace the rear of the four-module desktop stack against racking, but they
do not replace the four vertical corner clamps at each stack joint.

All pockets use the same 6 x 2 mm discs. A fully populated desktop build uses
64 magnets: 40 in 20 vertical stack/foot pairs, 16 in 8 rear-spine pairs, and
8 beneath the Pi screw heads. Side-seam magnets are only needed later when
pairing halves in a 19-inch rack.

Polarity is globally consistent: marked face up (+Z) for stack/foot magnets,
toward the rear (+Y) for module/spine pairs, and toward rack right (+X) for
future side-seam pairs. Pi polarity is not functional against steel, but
marked-face-up installation is preferred for consistency.

The six-plate project was validated and sliced natively with Bambu Studio
02.08.02.61. Its skeleton and skin line widths are explicit millimetre values,
which avoids the "Line width too large" / "100.000000" import error.

Bambu Studio may warn that the four full-height chassis have a "floating
cantilever." Its conservative overhang detector sees the short 45-degree seam
keys, socket roofs, and hollow tower caps. The UCG, both USW modules, and
dual-Pi chassis have no slicer-classified bridge longer than 17.52 mm.
Automatic supports fill large empty areas to reach those small surfaces, add
substantial print time, and obstruct the pockets. Print plate 1 first, then
keep supports disabled for the full-height production chassis if its
seam-tower coupons print cleanly.

The redesigned Pi drawers, vent insert, and UK-Ultra top slice without
warnings. Their independently measured maximum bridge spans are 6.39 mm,
12.40 mm, and 16.74 mm respectively.

Plate 1 is explicitly axis-aligned rather than automatically rotated. Its
maximum bridge is 18.84 mm, with 12.58 mm on the fit coupon, no bridge paths on
the polarity key, and 12.23 mm on each rear spine.

Plate 5 keeps the right USW module at exact 0-degree XY rotation. The print
face is unchanged, but this avoids a slicer-only diagonal bridge path that
appeared with a near-180-degree transform; the validated maximum is 17.52 mm.

All 20 packaged STLs were also sliced independently with native Bambu Studio:
20 pass, no unexpected warnings, and no bridge over 18.84 mm. The unchanged
chassis warning is matched by exact male/female seam-tower coupons generated
from the same OpenSCAD modules; those coupons slice without warnings at
4.66 mm and 7.10 mm maximum bridge.

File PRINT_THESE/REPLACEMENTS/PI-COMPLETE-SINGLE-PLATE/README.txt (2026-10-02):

PI COMPLETE SINGLE-PLATE A1 PROJECT
===================================

Print this project for all remaining Pi hardware:

  homelab-rack-Pi-Complete-Single-Plate-A1.3mf

It contains exactly:

  1. 04_Dual_Pi_Chassis_5mm_HAT_Clearance.stl
  2. 05_Pi_Drawer_1_6mm_Magnet_Fit.stl
  3. 06_Pi_Drawer_2_6mm_Magnet_Fit.stl

The vent is intentionally excluded because it has already been printed.
No existing replacement STL or project is modified by this package.

The chassis retains its validated orientation and two build-plate-only manual
support strips beneath the raised outer Pi-bay front rails. Both strips are
open to the front and can be removed from outside the empty chassis before
installing the drawers. No support reaches either drawer.

The drawers are rotated only around Z while remaining on their validated
support-free print faces. Their bounding boxes have 7.20 mm horizontal
clearance. The nearest chassis-to-drawer clearance is 9.60 mm.

Pinned native Bambu Studio 02.08.02.61 A1 estimate:

  Material: 143.52 g PLA
  Time:     6h27m32s
  Bridge:   17.52 mm maximum classified span

The native reopen/reslice reproduced 143.52 g and the same bridge maximum
without warnings; Bambu recalculated the time as 6h27m19s.

Evidence:

  pi_complete_single_plate_bed.png
  pi_complete_support_toolpaths.png
  slice-estimate.json
  object-inventory.json
  bridge-audit.json
  support-audit.json
  protected-hashes.json
  PI_COMPLETE_SINGLE_PLATE_AUDIT.json

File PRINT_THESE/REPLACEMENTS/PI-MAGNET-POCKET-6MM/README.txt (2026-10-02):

PI DRAWER 6 MM MAGNET GLUE-FIT REPLACEMENTS
============================================

These replace both Pi drawers only:

  05_Pi_Drawer_1_6mm_Magnet_Fit.stl
  06_Pi_Drawer_2_6mm_Magnet_Fit.stl

For Bambu A1 printing, open:

  homelab-rack-Pi-Drawers-6mm-Magnet-Fit.3mf

The chassis and vent remain unchanged. Do not reprint them for this correction.
The drawer envelopes, labels, rails, detents, board locators, magnetic gap,
screw-head clearance, and every chassis interface remain unchanged.

Each drawer has four revised underside magnet pockets:

  Straight glue-fit bore:       6.60 mm
  Underside bed-face mouth:     approximately 7.00 mm
  Support-free entrance flare:  0.70 mm high
  Magnet:                       nominal 6 x 2 mm
  Pocket depth:                 unchanged at 4.55 mm
  Insulating roof/skin:         unchanged at 0.30 mm
  Local boss outside diameter:  8.60 mm
  Nominal radial boss wall:     1.00 mm

The 7.0 mm flared entrance prevents first-layer elephant foot from reducing the
usable 6.6 mm bore. The boss diameter increases only around the four mounting
pockets; its height and mounting centers are unchanged.

MAGNET INSTALLATION

- These are glue-fit pockets, not press-fit pockets. Do not force the magnets.
- Confirm polarity against the chassis magnets before applying adhesive.
- Use a small amount of two-part epoxy or thick cyanoacrylate around the magnet
  edge. Keep adhesive away from the center of the insulating roof.
- Slide the magnet through the flared underside entrance and hold it gently
  against the pocket roof until the adhesive sets.
- Do not drill through or scrape the 0.30 mm insulating roof.

The existing pocket depth intentionally leaves room below a 2 mm magnet so it
can be inserted and glued against the roof. The replacement drawers are the
first article; no separate gauge or test plate is required.

Pinned combined estimate:

  30.32 g PLA
  1h47m54s

The project is support-free. Maximum classified bridge span is 6.32 mm.
A native reopen/reslice reproduced 30.32 g and the 6.32 mm bridge maximum
without supports or warnings; Bambu recalculated the time as 1h47m45s, nine
seconds lower. Detailed evidence is in PI_MAGNET_POCKET_6MM_AUDIT.json.

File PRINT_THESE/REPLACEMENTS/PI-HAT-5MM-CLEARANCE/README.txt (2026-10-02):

PI HAT +5 MM CLEARANCE REPLACEMENT
==================================

Print this replacement instead of 04_Dual_Pi_Chassis.stl:

  homelab-rack-Dual-Pi-Chassis-5mm-HAT-Clearance.3mf

The 3MF is the recommended Bambu A1 project. It contains one chassis and two
small build-plate-only manual support strips beneath the raised front top rails.
Remove both strips through the two open Pi bay fronts after printing.

Do not reprint either Pi drawer or the vent cartridge. The existing printed
drawers, magnetic holders, detents, guide lips, rails, and vent cartridge remain
compatible and unchanged.

Opening dimensions:

  Left Pi bay:   62 x 35 mm, bottom Z = 6 mm
  Center vent:   62 x 30 mm, bottom Z = 6 mm
  Right Pi bay:  62 x 35 mm, bottom Z = 6 mm

The outer openings extend exactly 5 mm higher than the original 30 mm openings.
The front cut continues through the existing 34 mm clearance depth and then
reaches the chassis's already-open interior. The original 30 mm drawer
faceplates intentionally leave a 5 mm headroom slot above each drawer.

The remaining front top rail is 2.7 mm high. The no-support A/B slice exposed
61.6 mm overhang-wall paths beneath these two rails, so the recommended 3MF
uses localized supports there only. The supports do not enter the detent
pockets, guide lips, drawer rails, center vent bay, magnetic holder geometry,
rack ears, stacking features, or open chassis interior.

No cosmetic eyebrow/filler is included because any clip occupying the 5 mm slot
would reduce the required coil insertion clearance.

If using either existing five-plate multi-plate project:

1. Open Plate 3.
2. Disable or delete only 04_Dual_Pi_Chassis.stl.
3. Leave 07_Vent_Insert.stl enabled if it has not already been printed.
4. Print the standalone replacement 3MF above.

If the vent is already printed, print only the standalone replacement project.

Pinned targeted-support estimate:

  113.22 g PLA
  4h50m34s

The no-support comparison was 107.12 g and 4h36m37s. The localized support
cost is 6.10 g and 13m57s.

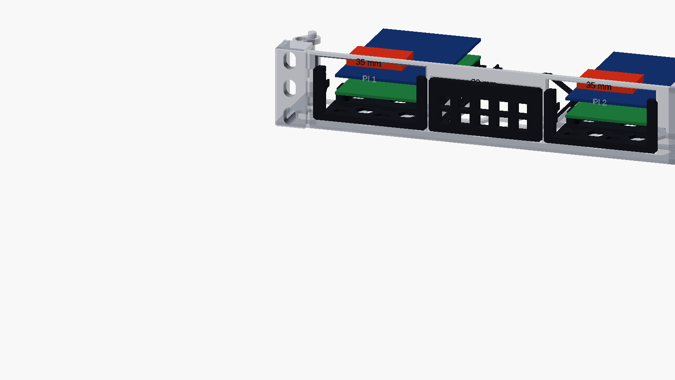
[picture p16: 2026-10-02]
PRINT_THESE/REPLACEMENTS/PI-HAT-5MM-CLEARANCE/pi_hat_5mm_clearance_front_cutaway.png

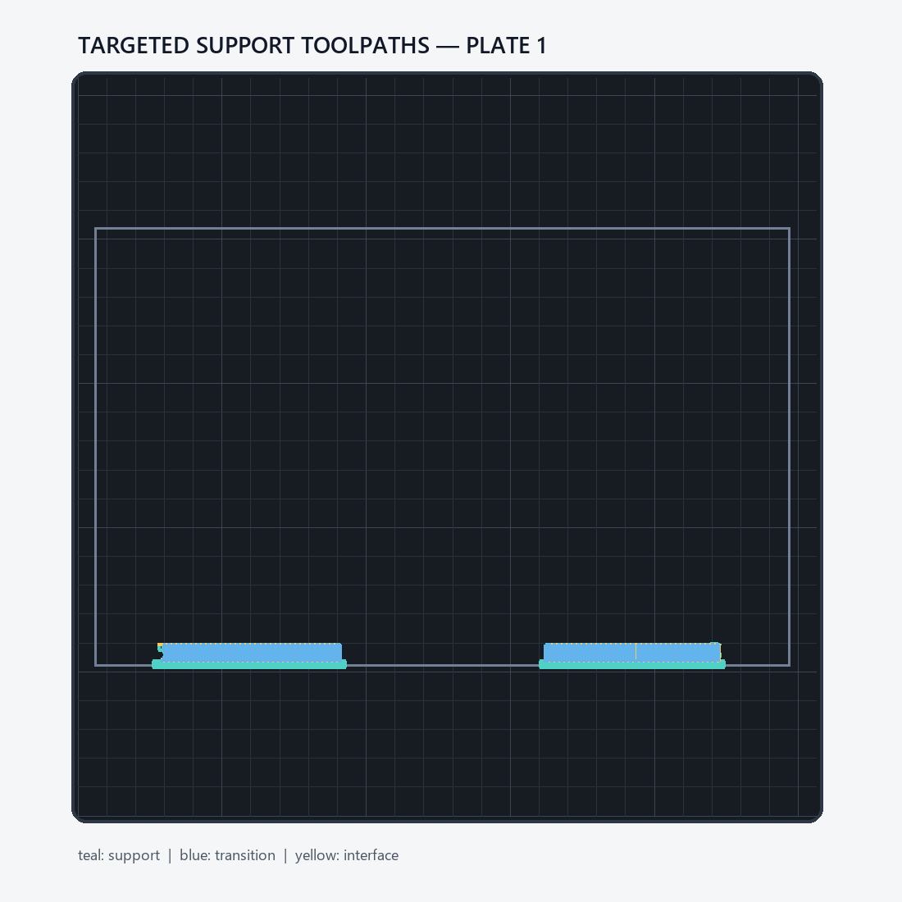
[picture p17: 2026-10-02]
PRINT_THESE/REPLACEMENTS/PI-HAT-5MM-CLEARANCE/support_toolpaths.png

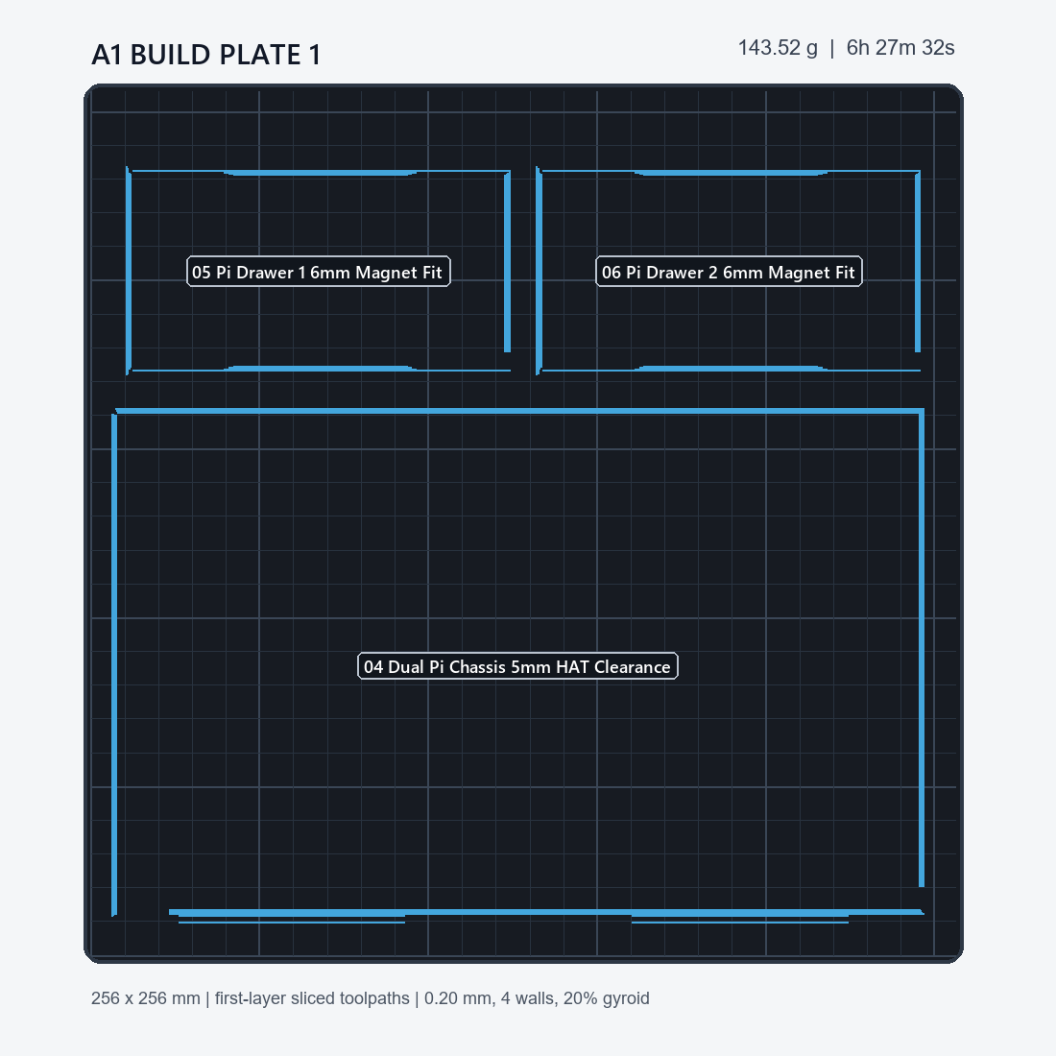
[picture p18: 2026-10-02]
PRINT_THESE/REPLACEMENTS/PI-COMPLETE-SINGLE-PLATE/pi_complete_single_plate_bed.png

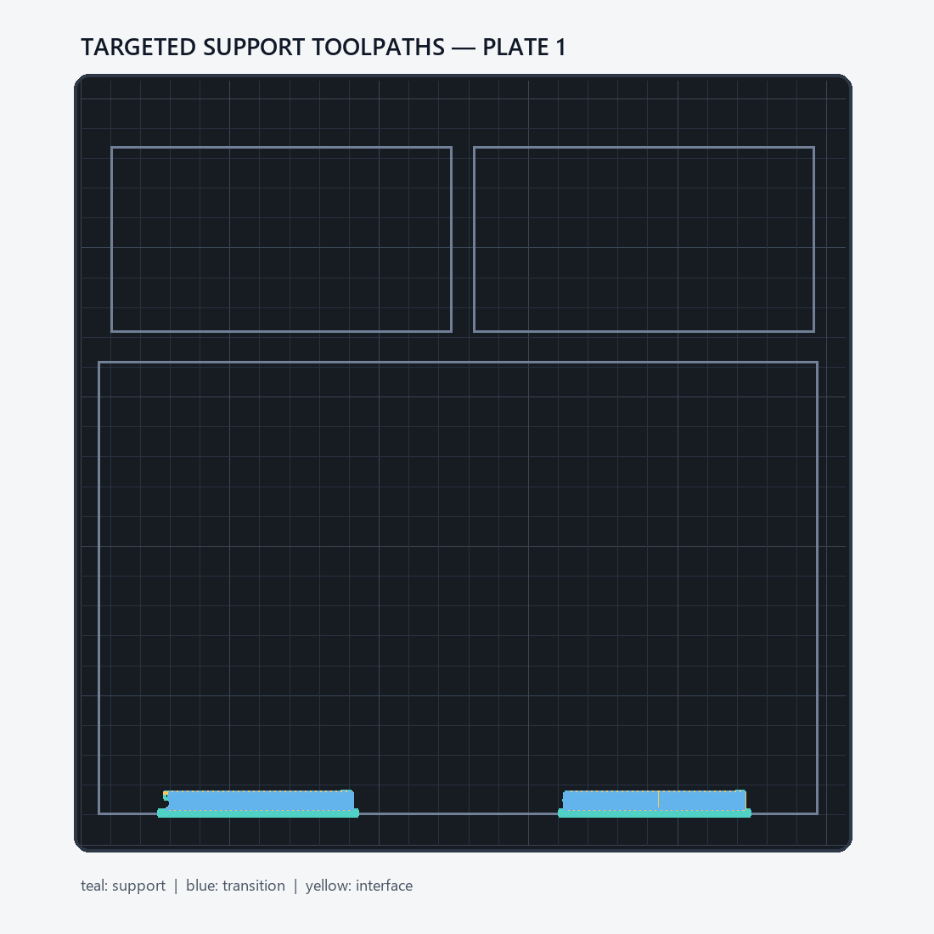
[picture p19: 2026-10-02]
PRINT_THESE/REPLACEMENTS/PI-COMPLETE-SINGLE-PLATE/pi_complete_support_toolpaths.png

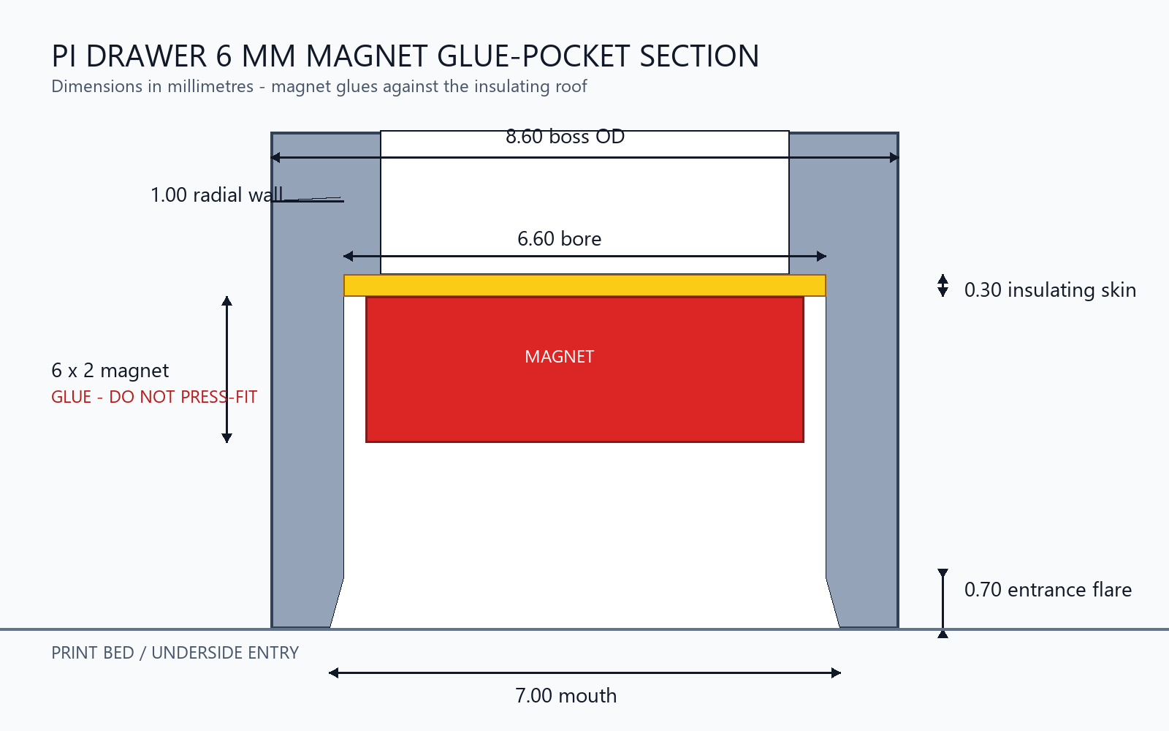
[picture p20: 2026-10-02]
PRINT_THESE/REPLACEMENTS/PI-MAGNET-POCKET-6MM/pi_magnet_pocket_6mm_section.png

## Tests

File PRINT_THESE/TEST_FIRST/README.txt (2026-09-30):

PRINT PLATE 1 FIRST
===================

Open plate_1-test.3mf. It stores plate 1 as independently arranged objects, so
every coupon and useful part remains inside the A1 build area and can be moved
or removed individually.

Plate 1 validates the important fits before committing 21h14m23s and 479.31 g
of PLA to production plates 2-6:

- 6 x 2 mm production glue-fit magnet pocket
- Tighter 6 x 2 mm diagnostic magnet pocket
- Peel-away stack registration tiles with a mating peg/socket and aligned
  6 x 2 mm magnet-pocket pair
- Reinforced side tower, diamond key, and matching socket
- Rack-ear slots
- Keystone cutout
- Pi-bay opening, receiving chamfer, service detents, guide lips, and
  removable full-depth vent cartridge
- Four removable desktop feet with optional 16 mm felt/rubber-pad recesses
- "UP" magnet polarity reference key

Use the normal production profile. Glue is still recommended for final magnet
installation even if the tighter diagnostic pocket appears to hold by friction.

The earlier connected-card peg and socket were independent gauges and could
not validate mating. On this revision, break the two narrow sprues and remove
the stack tiles. Flip the socket tile into assembly orientation and place it
over the peg tile. The peg/socket and magnet pockets then reproduce one exact
production stack pair. This geometry still requires physical validation; do
not record the earlier fixed-gauge print as a mating pass. The standalone
pockets continue to validate production and tighter diagnostic diameters.

Magnet orientation:

1. Choose either face of one magnet and mark it with a permanent marker.
2. Glue that magnet into the polarity key with the marked face visible beside
   the "UP" label.
3. Use the key to orient every loose magnet, marking the matching upward face.
4. Install stack and foot magnets with the marked face globally upward (+Z).
   On top pockets the mark remains visible; on bottom pockets it points into
   the part.
5. Install rear module/spine magnets with the marked face toward the rack rear
   (+Y). Install future side-seam magnets toward rack right (+X).
6. Pi magnet polarity does not affect steel attraction; marked face upward is
   preferred for consistency.

The feet are corner-specific because the peg and magnet have different offsets.
They only seat fully at the correct corner; never force them.

The included native plate keeps all parts axis-aligned and independently
selectable. Its longest slicer-classified bridge is 18.84 mm. The fit coupon's
functional features are carried by local bosses on a thin connected base, and
the polarity key uses a local magnet boss, avoiding broad unsupported top
skins.

The stack and bay checks remain available on this plate:

1. Break off and mate the two stack tiles. Confirm easy peg/socket engagement,
   face closure, lateral registration, and magnet clamping without rocking.
2. Insert the vent through the coupon. Confirm the runners do not bind, both
   detents click, the face seats flush, and an even pull releases it.

Loose-magnet attraction to all four assembled Pi/HAT screw heads has passed.
Do not print another coupon for the Pi mount. Use production Drawer 1 as the
first article, install its four magnets, seat the actual assembly, and verify
retention, insertion, locator engagement, and holder gap before Drawer 2.

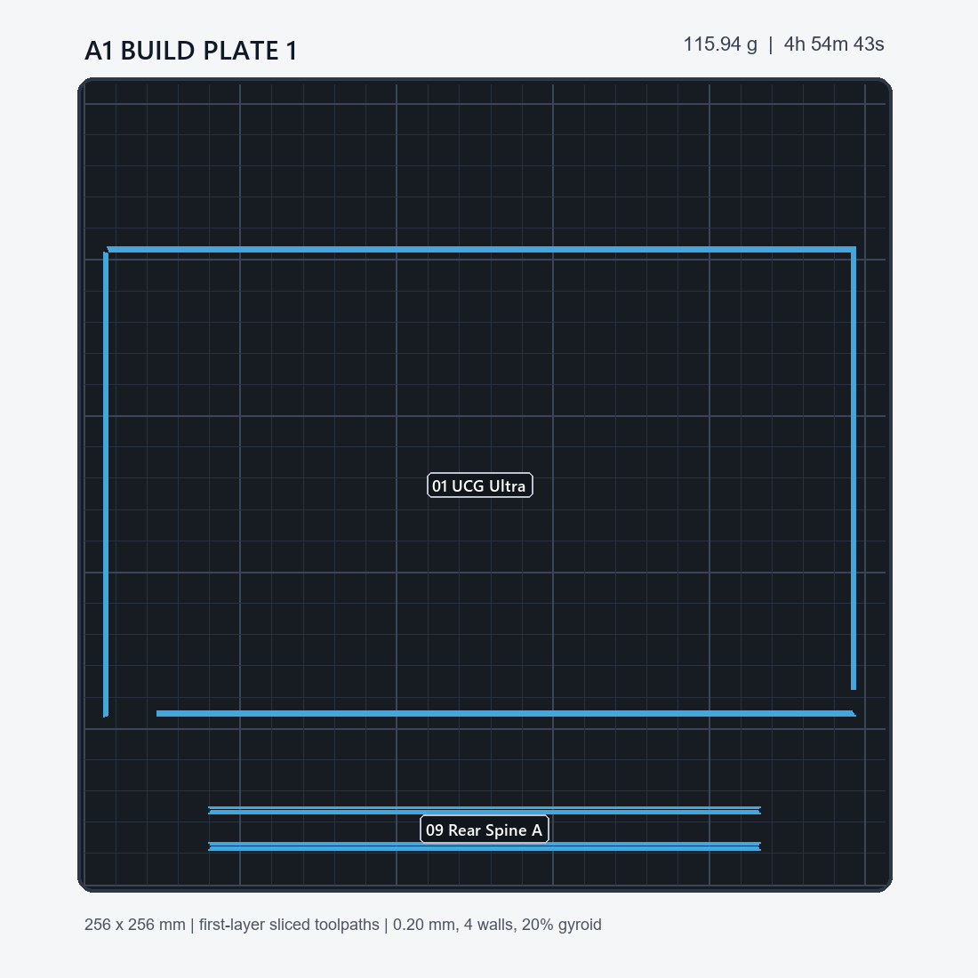
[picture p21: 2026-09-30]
renders/beds-no-test/bed_1.png

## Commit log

2026-09-30 Publish the validated homelab rack release
    Release the parameterized OpenSCAD design, test-first and production Bambu projects, independently validated printable files, reproducibility tooling, documentation, and interactive viewer.
    [01_Bay_Fit_Test.stl, 01_UCG_Ultra.stl, 02_Rear_Spine_A.stl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]
2026-09-30 Refine rack fit and Pi mounting
    Apply physical test feedback across the production release: remove the vent label, add keystone clearance and matching bay chamfers, convert the vent into a retained rail cartridge, correct seam and stack interfaces, and replace Pi snap posts with magnetic cradles. Regenerate and validate all affected CAD, STL, Bambu, audit, render, documentation, and viewer artifacts.
    Copilot-Session: 29508150-aad1-4098-a038-883206e1257f
    [01_Bay_Fit_Test.stl, 01_UCG_Ultra.stl, 02_USW_Ultra_Left.stl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]
2026-09-30 Add optimized five-plate no-test project
    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
    [homelab-rack-Bambu-Studio-5-plates-NO-TEST.3mf]
2026-09-30 Add targeted chassis support
    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
    [homelab-rack-Bambu-Studio-5-plates-NO-TEST-NO-SUPPORT.3mf, homelab-rack-Bambu-Studio-5-plates-NO-TEST.3mf]
2026-10-02 Add Pi HAT clearance replacement
    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
    [04_Dual_Pi_Chassis_5mm_HAT_Clearance.stl, homelab-rack-Dual-Pi-Chassis-5mm-HAT-Clearance.3mf, homelab_rack.scad]
2026-10-02 Add Pi drawer magnet-fit replacements
    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
    [05_Pi_Drawer_1_6mm_Magnet_Fit.stl, 06_Pi_Drawer_2_6mm_Magnet_Fit.stl, homelab-rack-Pi-Drawers-6mm-Magnet-Fit.3mf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]
2026-10-02 Add complete Pi single-plate project
    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
    [homelab-rack-Pi-Complete-Single-Plate-A1.3mf]
